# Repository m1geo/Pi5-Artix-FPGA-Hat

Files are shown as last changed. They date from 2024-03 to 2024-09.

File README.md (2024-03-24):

# Pi5-Artix-FPGA-Hat

An AMD/Xilinx Artix 50T FPGA on a Pi5 Hat with PCIe and GPIO interconnects as well as SPI programming using XC7A50T-2FGG484C.

The project uses a 4-layer PCB (which means some of the routing is a bit sub-optimal)!

The project includes pick-and-place and LCSC BoM files for JLCPCB PCBA services.

*Both SPI programming and PCIe have been tested and are functional.*

# Files

The PCB design files are inside the PCB folder, along with the schematic in the PCB/outputs/ folder.

The FPGA folder has a simple Blinky (flashing LED) and PCIe design based on the Xilinx Reference Design with some small mods.

The FPGA/Programmer/ folder has a script for programming the FPGA via spidev and lgpio using Xilinx Serial Slave (essentially SPI).

# Licence

MIT Licence. See the LICENCE file included for details.

Files inside FPGA/pcie_7x_0_ex/ are Copyright AMD/Xilinx. Seek their licence and terms of use if required.

# Support

This project comes without any support. Although I would like to help, I simply do not have the time to do so.

You can drop me a donation via PayPal if you have found the project useful: [PayPal Donation to M1GEO](https://www.paypal.com/paypalme/m1geo)

# Images

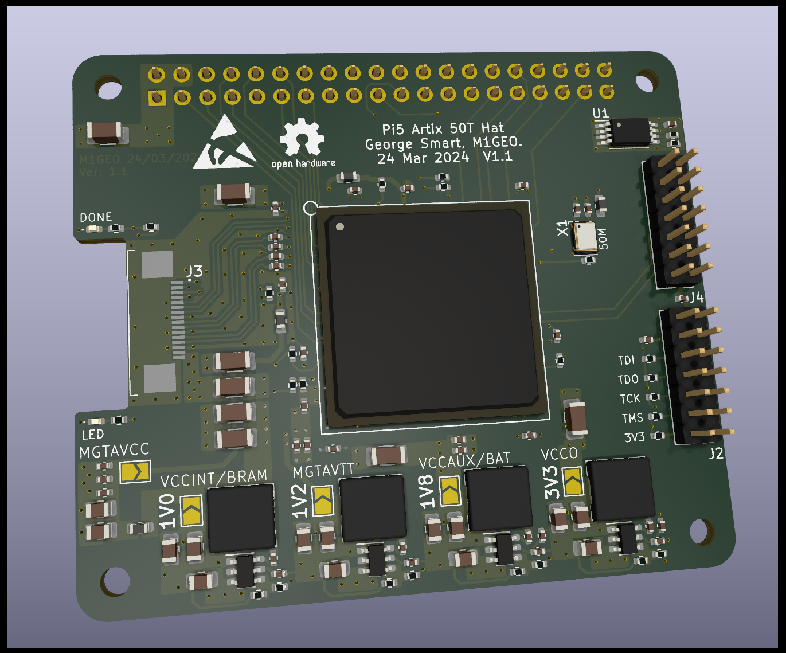
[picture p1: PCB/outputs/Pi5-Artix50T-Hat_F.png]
Front Render


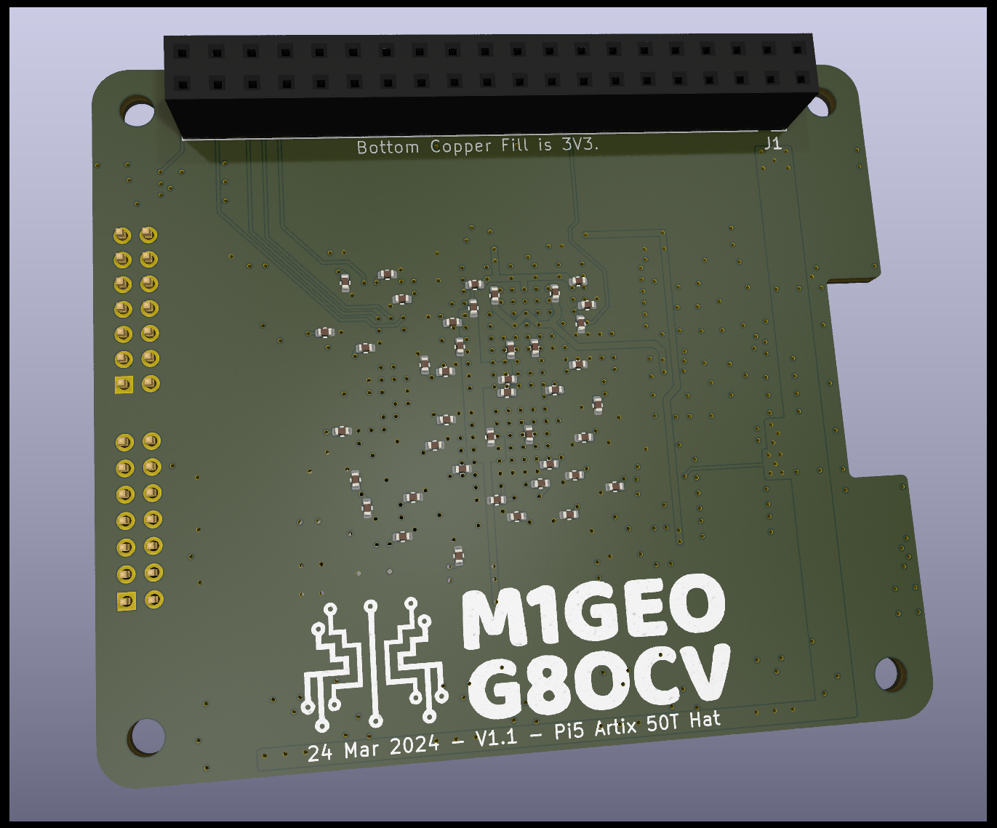
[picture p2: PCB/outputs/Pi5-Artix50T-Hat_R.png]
Rear Render


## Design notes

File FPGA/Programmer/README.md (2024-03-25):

# FPGA Programming Script Notes

Note that the `lgpio.gpiochip_open(n)` function changes between Pi4 and Pi5, with Pi4/CM4 being gpiochip 0 and Pi5 (devices with the RP1 chip) being gpiochip 4.

# FPGA Programming Script

The image below shows the entireity of the FPGA programming.

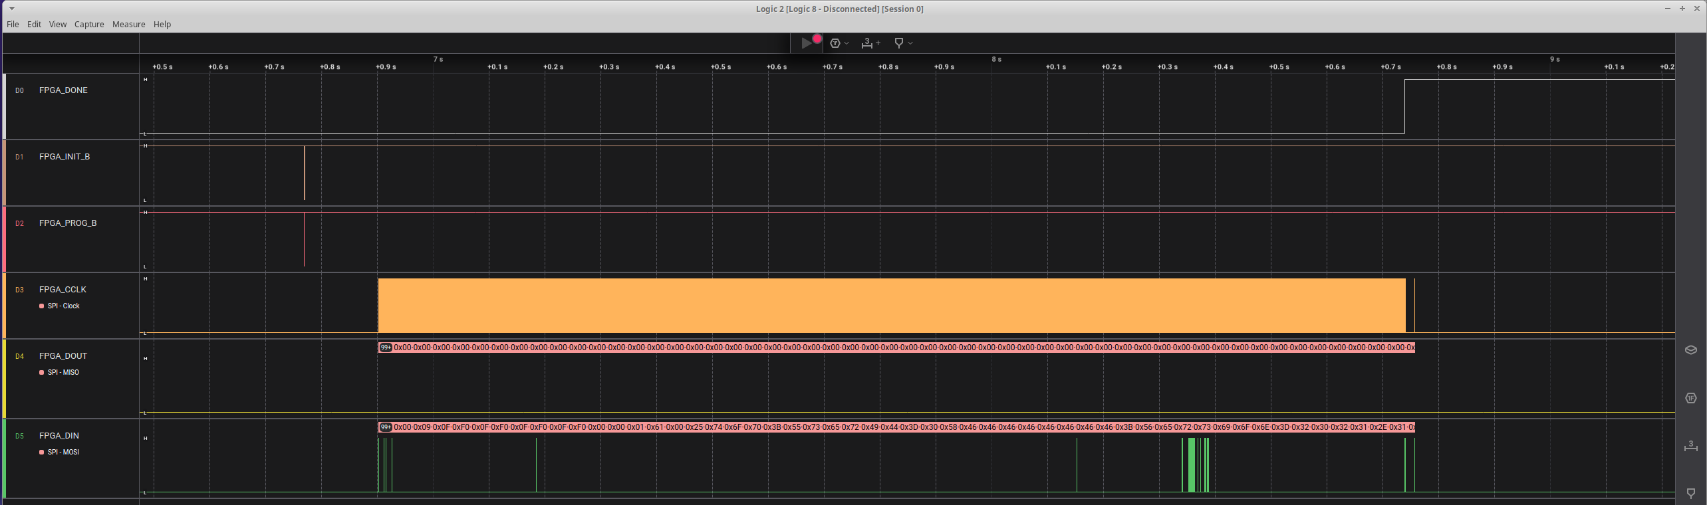
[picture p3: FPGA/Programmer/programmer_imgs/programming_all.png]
FPGA Progamming


# Init

* PROGRAM_B dropped low until INIT_B falls low, around 4us.
* Wait for INIT_B to rise, indicating FPGA is ready, around 570us.

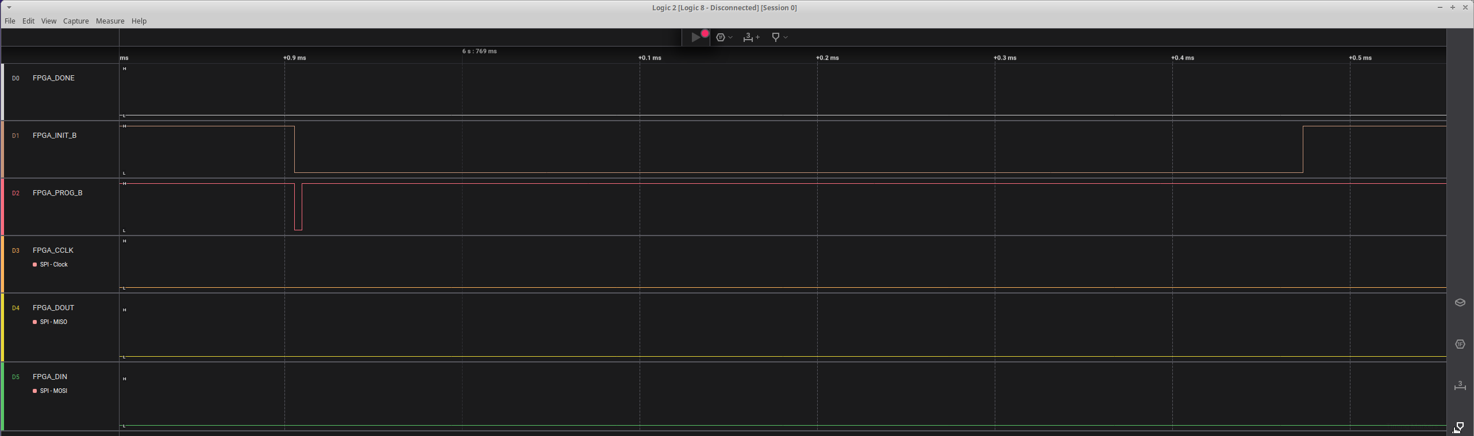
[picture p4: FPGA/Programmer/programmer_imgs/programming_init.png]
FPGA Progamming Init


# Sending the Bitfile

* Send the bitfile using SPI0 on the Pi5. The exact device doesn't matter as we aren't using the hardware chip select lines.
* The Xilinx diagrams show LSB-first. The text says to use MSB-first. The FPGA works with either. My code uses MSB-first as it's the SPI standard.
* The FPGA will happily program with a 100 MHz clock. I didn't try any faster. Debugging was done at 10 MHz.
* The Xilinx Diagrams show SPI Mode 0: that is, clock idle low, FPGA reading data on rising edge.

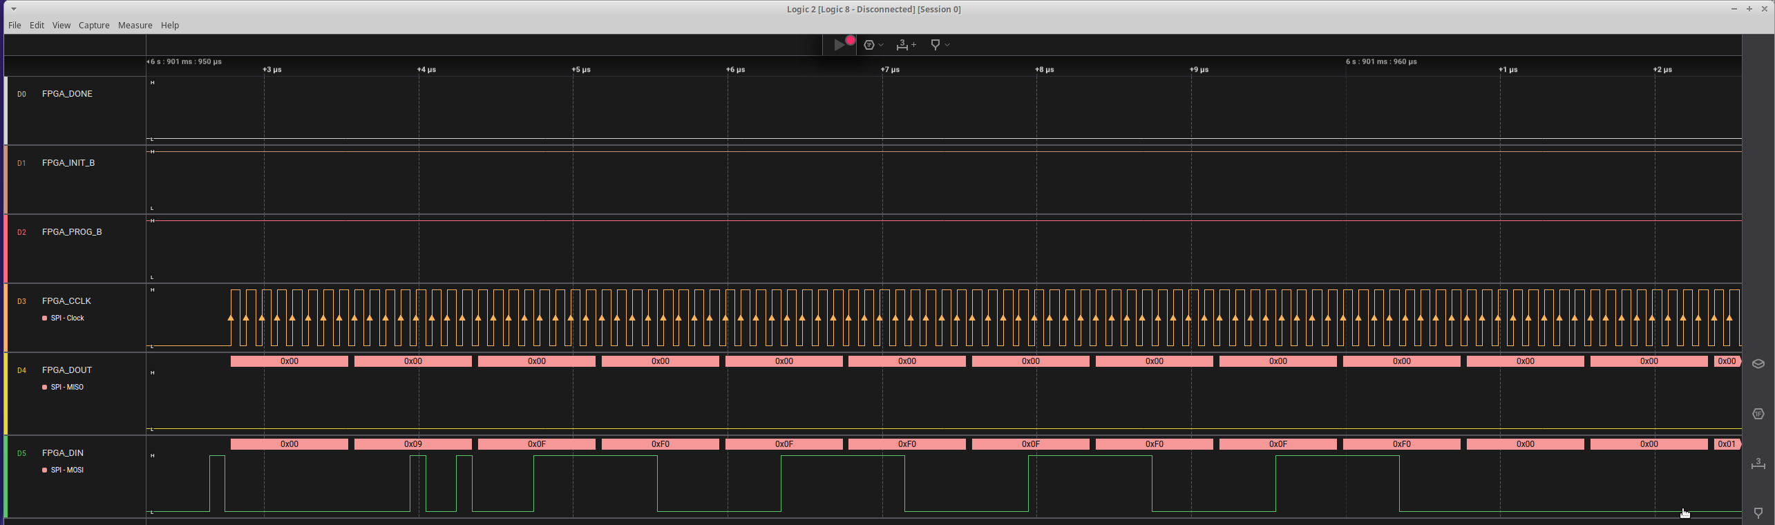
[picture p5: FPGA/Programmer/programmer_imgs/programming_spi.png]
FPGA Progamming SPI


Below shows a higlighed hexeditor view of the above SPI bytes.

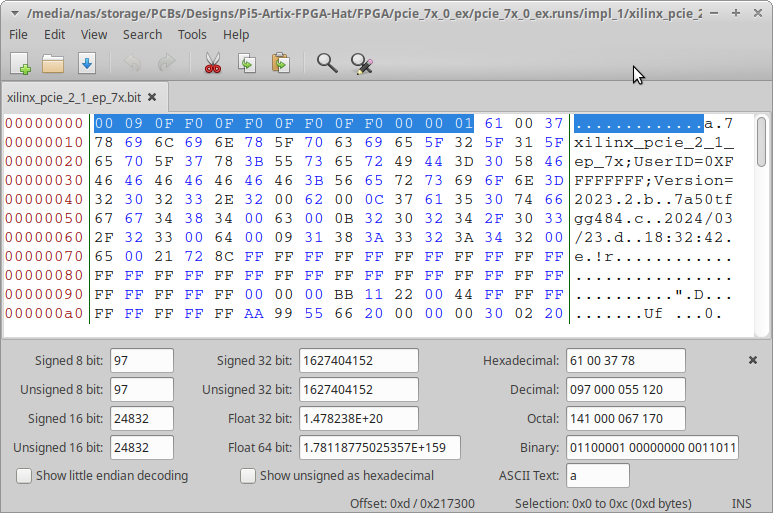
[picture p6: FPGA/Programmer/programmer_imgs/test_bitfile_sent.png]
Bitstream HEX


# Programming DONE

The programming DONE signal usually asserts before the end of the bit file. This is mentioned in the documentation.

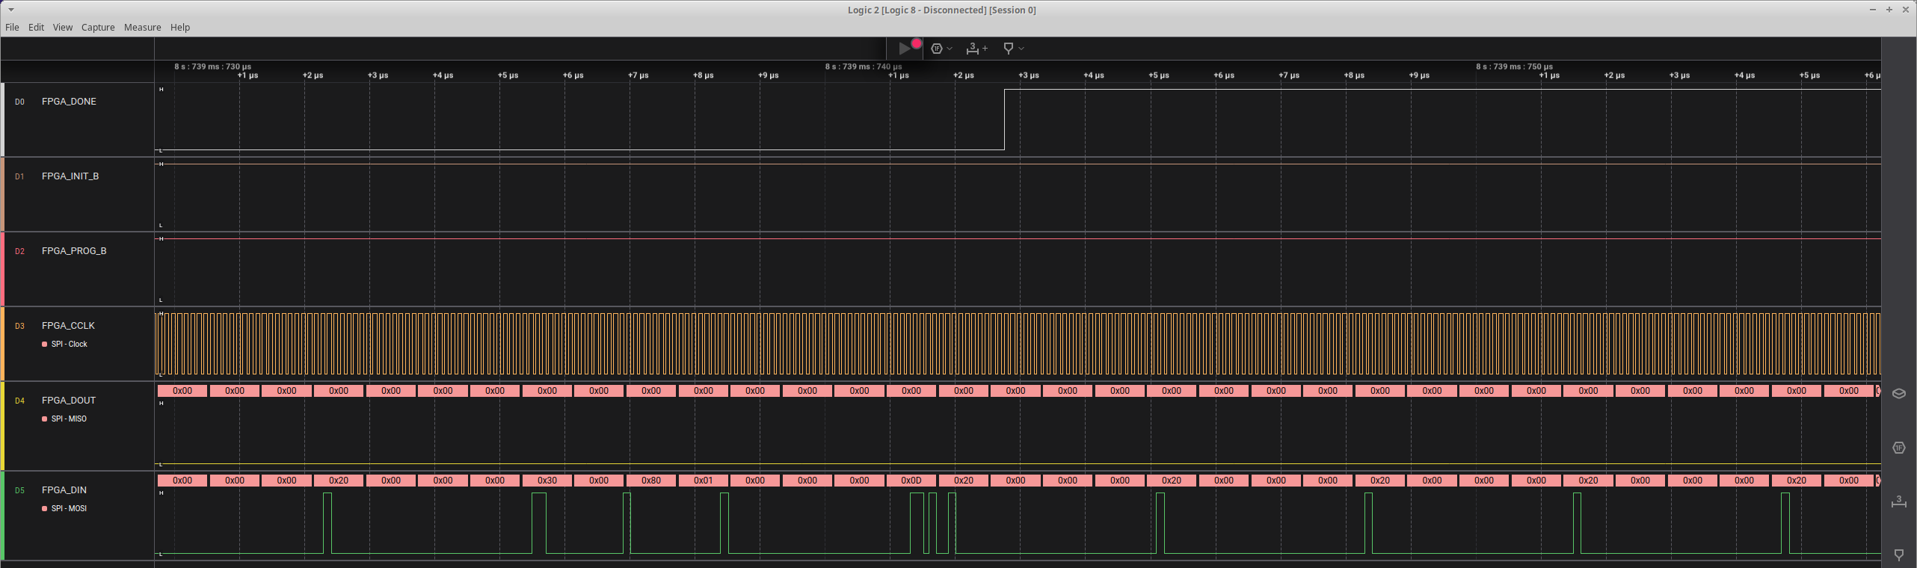
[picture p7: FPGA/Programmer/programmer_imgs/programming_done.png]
FPGA Progamming Done


# Special Start-Up Conditions

The Special Start-Up Conditions provisions for cases where the interal FPGA core needs a few external clock cycles to finish the configuration and setup process. This is referred to as compensating for 'Special Startup Conditions' and requires the Pi to send a further 8 clock cycles with DIN held high. This is accomplished by sending an 0xFF byte.

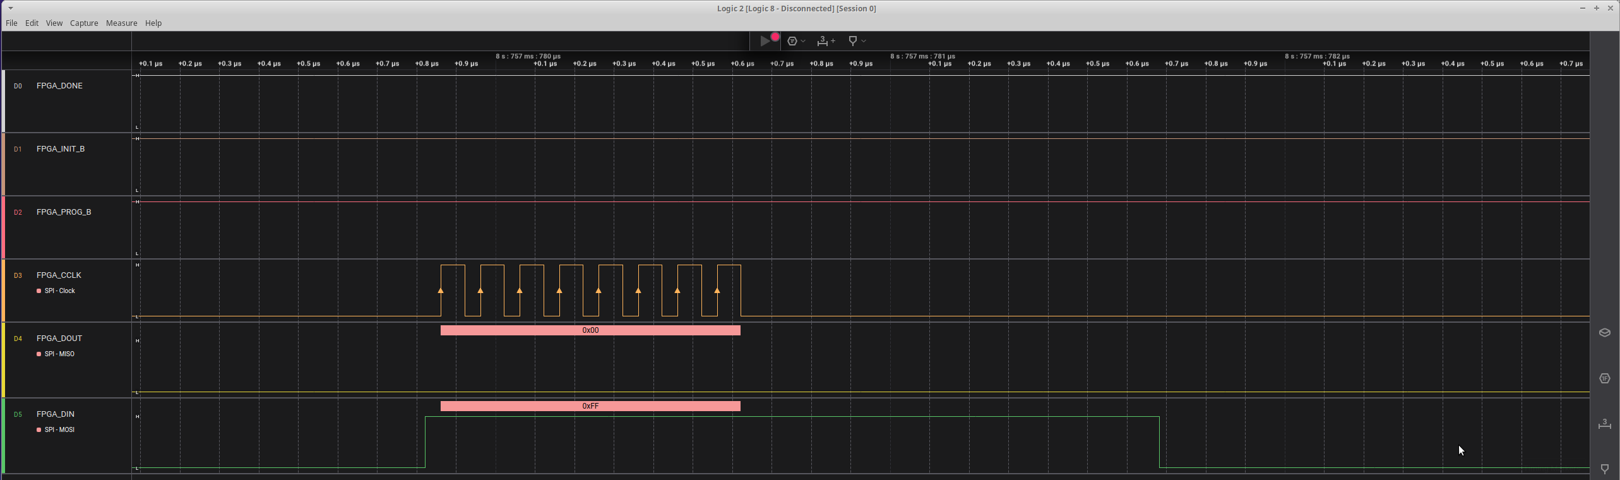
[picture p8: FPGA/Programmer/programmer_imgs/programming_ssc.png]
FPGA Progamming SSC


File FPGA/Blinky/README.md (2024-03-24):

# Blinky FPGA Image

This folder contains a bit file & sources that can be programmed using the programmer script into the FPGA.

It takes the 50 MHz reference clock and generates a 3 Hz LED flashing.  That's it. Simple.

No project here, but you can figure this one out!

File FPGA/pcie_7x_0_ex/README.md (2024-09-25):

# PCIe Gen2 x1 FPGA Image

This folder contains the Vivado project for a PCIe Gen2 x1 test system. It's simply the PCIe 7-Series Reference Design by Xilinx, with some small tweaks to make it work on the Pi5.

This design is recognised by Linux on the Ras Pi 5:

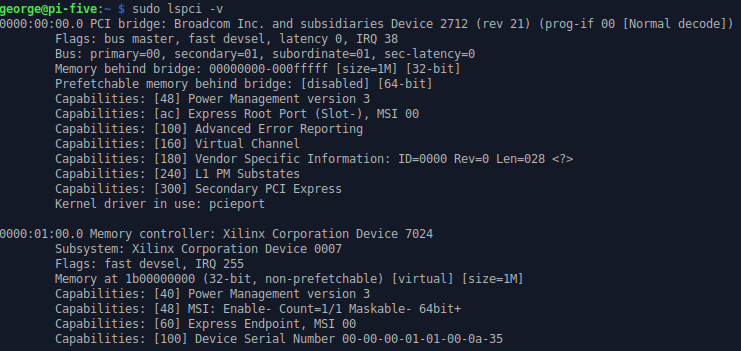
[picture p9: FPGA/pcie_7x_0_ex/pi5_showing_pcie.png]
Linux on Pi5 Showing FPGA via PCIe


# Rescanning the PCIe Bus

Once you have programmed the FPGA, the Pi will not immediately see it, since the Pi is a bit weird with hotplug detection, etc., so you'll need to run the following to kick the PCIe controller. Not really sure what this does, but, it works...

`echo 1000110000.pcie > /sys/bus/platform/drivers/brcm-pcie/bind` (Pi5)

`echo fd500000.pcie > /sys/bus/platform/drivers/brcm-pcie/bind` (Pi4/CM4)

# Legals

The files in the project mostly belong to AMD/Xilinx through their reference design. I am not asserting any claims over these files. They are provided for convenience.

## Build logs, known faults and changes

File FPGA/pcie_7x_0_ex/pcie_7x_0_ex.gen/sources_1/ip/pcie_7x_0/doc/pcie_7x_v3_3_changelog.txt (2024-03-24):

2023.2:
 * Version 3.3 (Rev. 20)
 * General: Rebrand to AMD copyright information
 * Revision change in one or more subcores

2023.1.2:
 * Version 3.3 (Rev. 19)
 * No changes

2023.1.1:
 * Version 3.3 (Rev. 19)
 * No changes

2023.1:
 * Version 3.3 (Rev. 19)
 * Revision change in one or more subcores

2022.2.2:
 * Version 3.3 (Rev. 18)
 * No changes

2022.2.1:
 * Version 3.3 (Rev. 18)
 * No changes

2022.2:
 * Version 3.3 (Rev. 18)
 * Revision change in one or more subcores

2022.1.2:
 * Version 3.3 (Rev. 17)
 * No changes

2022.1.1:
 * Version 3.3 (Rev. 17)
 * No changes

2022.1:
 * Version 3.3 (Rev. 17)
 * General: Added pcie id interface and corresponding signals
 * Revision change in one or more subcores

2021.2.2:
 * Version 3.3 (Rev. 16)
 * No changes

2021.2.1:
 * Version 3.3 (Rev. 16)
 * No changes

2021.2:
 * Version 3.3 (Rev. 16)
 * Revision change in one or more subcores

2021.1.1:
 * Version 3.3 (Rev. 15)
 * No changes

2021.1:
 * Version 3.3 (Rev. 15)
 * Revision change in one or more subcores

2020.3:
 * Version 3.3 (Rev. 14)
 * No changes

2020.2.2:
 * Version 3.3 (Rev. 14)
 * No changes

2020.2.1:
 * Version 3.3 (Rev. 14)
 * No changes

2020.2:
 * Version 3.3 (Rev. 14)
 * General: Added Zynq 7z030i,7z035i,7z045i and 7z100i device support
 * Revision change in one or more subcores

2020.1.1:
 * Version 3.3 (Rev. 13)
 * No changes

2020.1:
 * Version 3.3 (Rev. 13)
 * Revision change in one or more subcores

2019.2.2:
 * Version 3.3 (Rev. 12)
 * No changes

2019.2.1:
 * Version 3.3 (Rev. 12)
 * No changes

2019.2:
 * Version 3.3 (Rev. 12)
 * Revision change in one or more subcores

2019.1.3:
 * Version 3.3 (Rev. 11)
 * No changes

2019.1.2:
 * Version 3.3 (Rev. 11)
 * No changes

2019.1.1:
 * Version 3.3 (Rev. 11)
 * No changes

2019.1:
 * Version 3.3 (Rev. 11)
 * General: Added new device xa7k160t.
 * Revision change in one or more subcores

2018.3.1:
 * Version 3.3 (Rev. 10)
 * No changes

2018.3:
 * Version 3.3 (Rev. 10)
 * Bug Fix: Fixed JTAG debugger Issue.
 * Bug Fix: Added waviers for lint errors.
 * Revision change in one or more subcores

2018.2:
 * Version 3.3 (Rev. 9)
 * Bug Fix: Updated MSIX TABLE & PBA OFFSET parameters. Which effects MSI-X functionality
 * Revision change in one or more subcores

2018.1:
 * Version 3.3 (Rev. 8)
 * General: Added support for xa7a12t(cpg238,csg325) and xa7a25t(cpg238,csg325) devices
 * Revision change in one or more subcores

2017.4:
 * Version 3.3 (Rev. 7)
 * General: Removed 'xx' in the Interface values
 * Revision change in one or more subcores

2017.3:
 * Version 3.3 (Rev. 6)
 * Bug Fix: Updated arrow colors for JTAG debugger LTSSM graph
 * Feature Enhancement: Enabled support for cpg238 package for devices - xc7a12t,xc7a12ti,xc7a12tl,xc7a25t,xc7z25ti and xc7a25tl
 * Revision change in one or more subcores

2017.2:
 * Version 3.3 (Rev. 5)
 * Revision change in one or more subcores

2017.1:
 * Version 3.3 (Rev. 4)
 * Bug Fix: Removed unwanted display messages
 * Bug Fix: Removed option to select 250Mhz of UserClk_freq (AXI Interface Frequency) for the devices xc7z015,xc7z15i and xc7z12s since the timing does not meet
 * Feature Enhancement: Added JTAG debugger support to debug LTSSM, Reset sequence and Rx detect sequence.User option is added in the 'Add.Debug Options' GUI page
 * Revision change in one or more subcores

2016.4:
 * Version 3.3 (Rev. 3)
 * General: Added support for xc7a12tl and xc7a25tl devices
 * Revision change in one or more subcores

2016.3:
 * Version 3.3 (Rev. 2)
 * Bug Fix: Updated text in core configuration GUI to display Capabilities Register value as 0x0142 when Slot Implemented option is selected for Rootport Mode
 * Other: Added support for xc7a12t,xc7a12t,xc7a25t,xc7a25ti and xc7z012s devices
 * Revision change in one or more subcores

2016.2:
 * Version 3.3 (Rev. 1)
 * Reduced the number of characters on a single line by making a multi-line attribute assignment.
 * Added CDC registers to the pl_phy_lnk_up and pl_received_hot_rst PCIe outputs.
 * Revision change in one or more subcores

2016.1:
 * Version 3.3
 * Modified the width of pipe_tx_*_sigs, common_commands_in and common_commands_out
 * Added Tandem support for xc7z035
 * Modified the mapping of logical and physical external pipe interface ports for End Point configurations so that it can be connected to Root Port instance directly
 * Fixed issue with the default values of 'Base Class Menu' and 'Sub Class Interface Menu' and 'Class Code' update when Lookup Assistant option is used
 * Removed the dependency of 'Include Shared Logic(clocking)in example design' on 'External PIPE Interface' pipe mode simulation option.No changes made to the 'Enable Pipe mode Simulation' option
 * Revision change in one or more subcores

2015.4.2:
 * Version 3.2 (Rev. 1)
 * No changes

2015.4.1:
 * Version 3.2 (Rev. 1)
 * No changes

2015.4:
 * Version 3.2 (Rev. 1)
 * Fixed unresolved instances of sys_clk_gen used in pipe mode simulations. This module is now delivered in 'source' directory

2015.3:
 * Version 3.2
 * For EXTERNAL PIPE INTERFACE mode, a new file xil_sig2pipe.v is delivered in the simulation directory and it replaces the phy_sig_gen.v. BFM/VIP’s should interface with the xil_sig2pipe instance in board.v
 * IP revision number added to HDL module, library, and include file names, to support designs with both locked and upgraded IP instances
 * Revision change in one or more subcores

2015.2.1:
 * Version 3.1 (Rev. 1)
 * No changes

2015.2:
 * Version 3.1 (Rev. 1)
 * Fixed GTP DRP write issue - (Xilinx Answer 62770)
 * Added support for xq7z100 device
 * Added support for Post Synthesis/Implementation netlist simulation for EP/Verilog mode, for non-PIPE mode only

2015.1:
 * Version 3.1
 * Added support for xc7a35ti,xc7a50ti,xc7a75ti,xc7a100ti and xc7a200ti devices.
 * Added non-default input port pipe_txinhibit.
 * Fixed issue with invalid link width and speeds for -1 speed grade for devices xc7z030i and xc7z015i devices (x8 is not supported and incase of xc7z015i only Gen1 speeds are supported when speedgrade -1 is selected).
 * Added support for new packages: fbv484,fbv676,ffv1156,ffv900,fbv900 and ffv901
 * Added shared logic support for RP configuration.
 * Modified the External Pipe Interface as Master for Rootport configuration and Slave for Endpoint and Legacy Endpoint configurations.
 * Update to generate a 100MHz icap_clk for tandem configurations rather than using the ref_clk input.
 * Removed 250Mhz User clock frequency option for all -1,-1I,-1M,-1Q,-1L speedgrades of Artix7 family.

2014.4.1:
 * Version 3.0 (Rev. 4)
 * No changes

2014.4:
 * Version 3.0 (Rev. 4)
 * Enhancement to allow debug cores to work better within Tandem designs. Build_stage1.tcl now runs befor place_design and handles bscan primitives.
 * Added support for Artix7 xc7a15t, xc7a15tl and xa7a15t devices
 * Added support for Zynq xc7z035 device
 * Changed the pipe mode simulation options in GUI to radio buttons (No change in the functionality)

2014.3:
 * Version 3.0 (Rev. 3)
 * Enabled PIPE Sim support for Root Port configuration
 * Added support for Kintex7 Low voltage (0.9v) variants, for only Gen1 speed
 * Added support for Kintex7 Defense grade Low voltage (0.9v) variants, for only Gen1 speed
 * Fixed CPLL Power spike on power up issue (AR59294)

2014.2:
 * Version 3.0 (Rev. 2)
 * Added AZynq7030 device support
 * Added QArtix 50t device support
 * Enabled PIPE simulation and External PIPE interface support only when shared logic option Shared Logic (clocking) in example design is selected

2014.1:
 * Version 3.0 (Rev. 1)
 * Added Zynq7015 device support
 * Added 35t,50t and 75t support for Artix7l and Aartix7 devices
 * Added cpg236 and csg325 packages support for Artix7 devices
 * Enabled Tandem PROM configuration support for Zynq 7030 and for Zynq7045 devices
 * Enabled Tandem Configuration support for Kintex 420T device
 * Changed the directory structure of the core without affecting the design hierarchy

2013.4:
 * Version 3.0
 * Added XC7Z200TSBG484 device support
 * Added support Artix7 35t, 50t and 75t devices
 * Added port level enablement for icap and startup signal interfaces
 * Added 3 new ports - pipe_rxstatus, pipe_eyescandataerror and pipe_dmonitordout to the transceiver debug interface
 * Added logic to power down CPLL until it is required during the PCIe link bring-up

2013.3:
 * Version 2.2
 * Reduced Warnings in Simulations
 * Reduced Warnings in Synthesis
 * Implemented Shared Logic for Clocking and Transeciver GT Common blocks to include either in core or example design
 * Implemented Tarnsceiver Core Debug interface. Brought the debug signals to the port level
 * Brought the Ext GT DRP signals upto the core top port level
 * Added support for IPI integrator
 * Updated xdc to match IP hierarchy
 * Added support for Cadence IES and Synopsys VCS Simulators
 * Added support for upgrade from previous versions
 * Added support for Zynq 7100 device
 * Added new pages Shared Logic and Core interface Parameters in GUI in Advanced mode
 * Added Enablement of PCIe DRP interface and made the option true by default
 * PCIe Sideband interface is broken into several smaller interfaces to connect with DMA IP in IPI
 * Added support for External PIPE interface mode

2013.2:
 * Version 2.1
 * Enhancements in the Tandem Logic - added STARTUP Premitive and new ports related to this premitive (static ports)
 * Removed the redundant blocks related to Tandem configuration logic
 * Added AER_CAP_ECRC_GEN_CAPABLE parameter in XGUI
 * Added option to select the Internal or external clocking module (Parameter PCIE_EXT_CLK)
 * Marked Artix7 (fgg484 and fbg484) and Zynq devices as production. Added GES_and_Production option for Silicon_Rev parameter. Updated the Auto-Upgrade Script
 * Added support for Artix7 and Kintex7 Lowvoltage family
 * Shortened the example design xdc file name (PG updated)
 * IPI Level 0 Support
 * Added OOC flow support
 * Fixed CDC issues with GT wrappers
 * Removed the BETA tag for Tandem PROM and Tandem PCIe options
 * For x8g1, 128-bit interface width configuration, Removed the optional 250MHz. Updated the Auto-upgrade script

2013.1:
 * Version 2.0
 * Lower case ports for Verilog
 * Added Zynq Support
 * Fixed Reset Sequence issue with GTPs
 * Fixed TXOUTCLK flatline issue
 * Fixed the issue with GUI to select the optional frequency for g2x4, 128-bit configuration. Now the selection for 250Mhz optional frequency is removed as it is not supported configuration
 * Fixed XSIM issues with VHDL version of the core
 * Changed upper case portlevel signals to lower case (clocking interface for partial re-configuration and ICAP interface)
 * Added pipe_mmcm_rst_n signal at the port level as input in the core top file.
 * All Kintex devices, Virtex 2000T, Artix 100t/ffg676, 200T/fbg676,ffg1156 are marked as Production. Option is added in GUI to select GES_and_Production
 * Tandem Configuration - The option is enabled independent of the Dev board selection for Kintex 325/ffg900 and Virtex 485/ffg1761/PCIe Block X1Y0
 * Tandem Confguration - Create Bin files for stage 2, Back Up & restore of bitstream generation settings

(c) Copyright 2002 - 2023 Advanced Micro Devices, Inc. All rights reserved.

This file contains confidential and proprietary information
of AMD and is protected under U.S. and international copyright
and other intellectual property laws.

DISCLAIMER
This disclaimer is not a license and does not grant any
rights to the materials distributed herewith. Except as
otherwise provided in a valid license issued to you by
AMD, and to the maximum extent permitted by applicable
law: (1) THESE MATERIALS ARE MADE AVAILABLE "AS IS" AND
WITH ALL FAULTS, AND AMD HEREBY DISCLAIMS ALL WARRANTIES
AND CONDITIONS, EXPRESS, IMPLIED, OR STATUTORY, INCLUDING
BUT NOT LIMITED TO WARRANTIES OF MERCHANTABILITY, NON-
INFRINGEMENT, OR FITNESS FOR ANY PARTICULAR PURPOSE; and
(2) AMD shall not be liable (whether in contract or tort,
including negligence, or under any other theory of
liability) for any loss or damage of any kind or nature
related to, arising under or in connection with these
materials, including for any direct, or any indirect,
special, incidental, or consequential loss or damage
(including loss of data, profits, goodwill, or any type of
loss or damage suffered as a result of any action brought
by a third party) even if such damage or loss was
reasonably foreseeable or AMD had been advised of the
possibility of the same.

CRITICAL APPLICATIONS
AMD products are not designed or intended to be fail-
safe, or for use in any application requiring fail-safe
performance, such as life-support or safety devices or
systems, Class III medical devices, nuclear facilities,
applications related to the deployment of airbags, or any
other applications that could lead to death, personal
injury, or severe property or environmental damage
(individually and collectively, "Critical
Applications"). Customer assumes the sole risk and
liability of any use of AMD products in Critical
Applications, subject only to applicable laws and
regulations governing limitations on product liability.

THIS COPYRIGHT NOTICE AND DISCLAIMER MUST BE RETAINED AS
PART OF THIS FILE AT ALL TIMES.

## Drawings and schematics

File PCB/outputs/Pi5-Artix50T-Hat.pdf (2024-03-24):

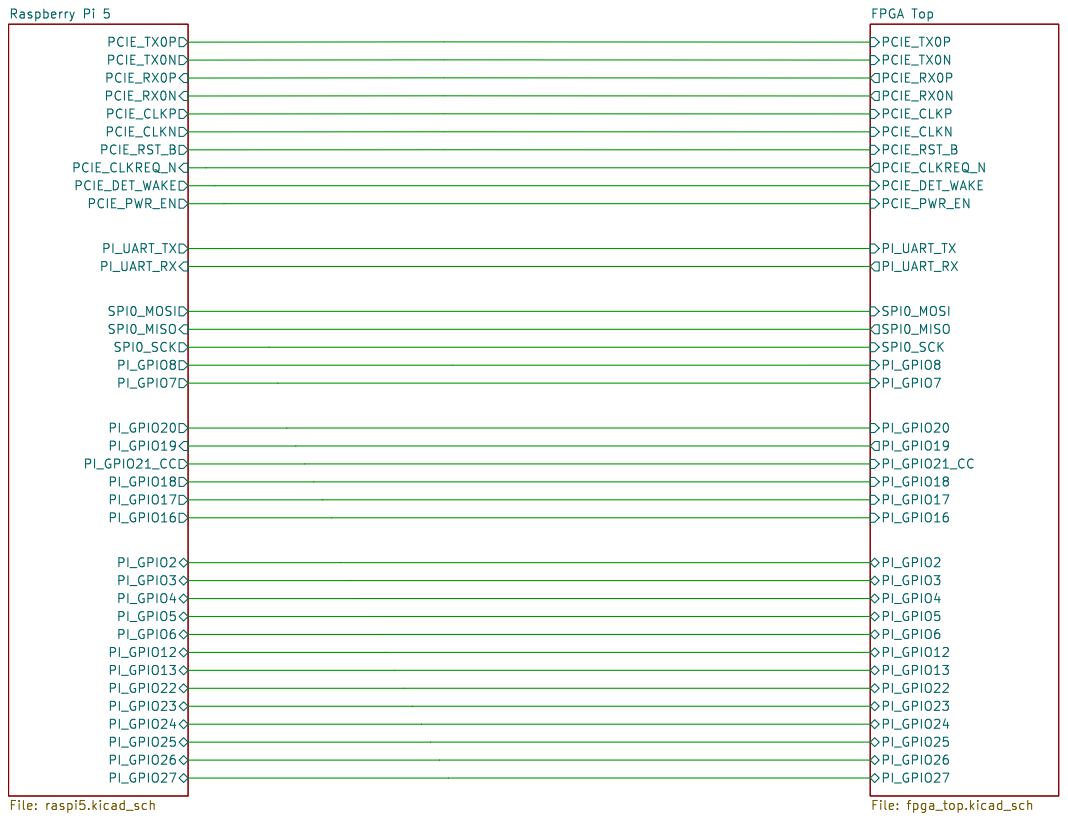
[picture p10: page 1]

https://www.george-smart.co.uk
https://github.com/m1geo/Pi5-Artix-FPGA-Hat

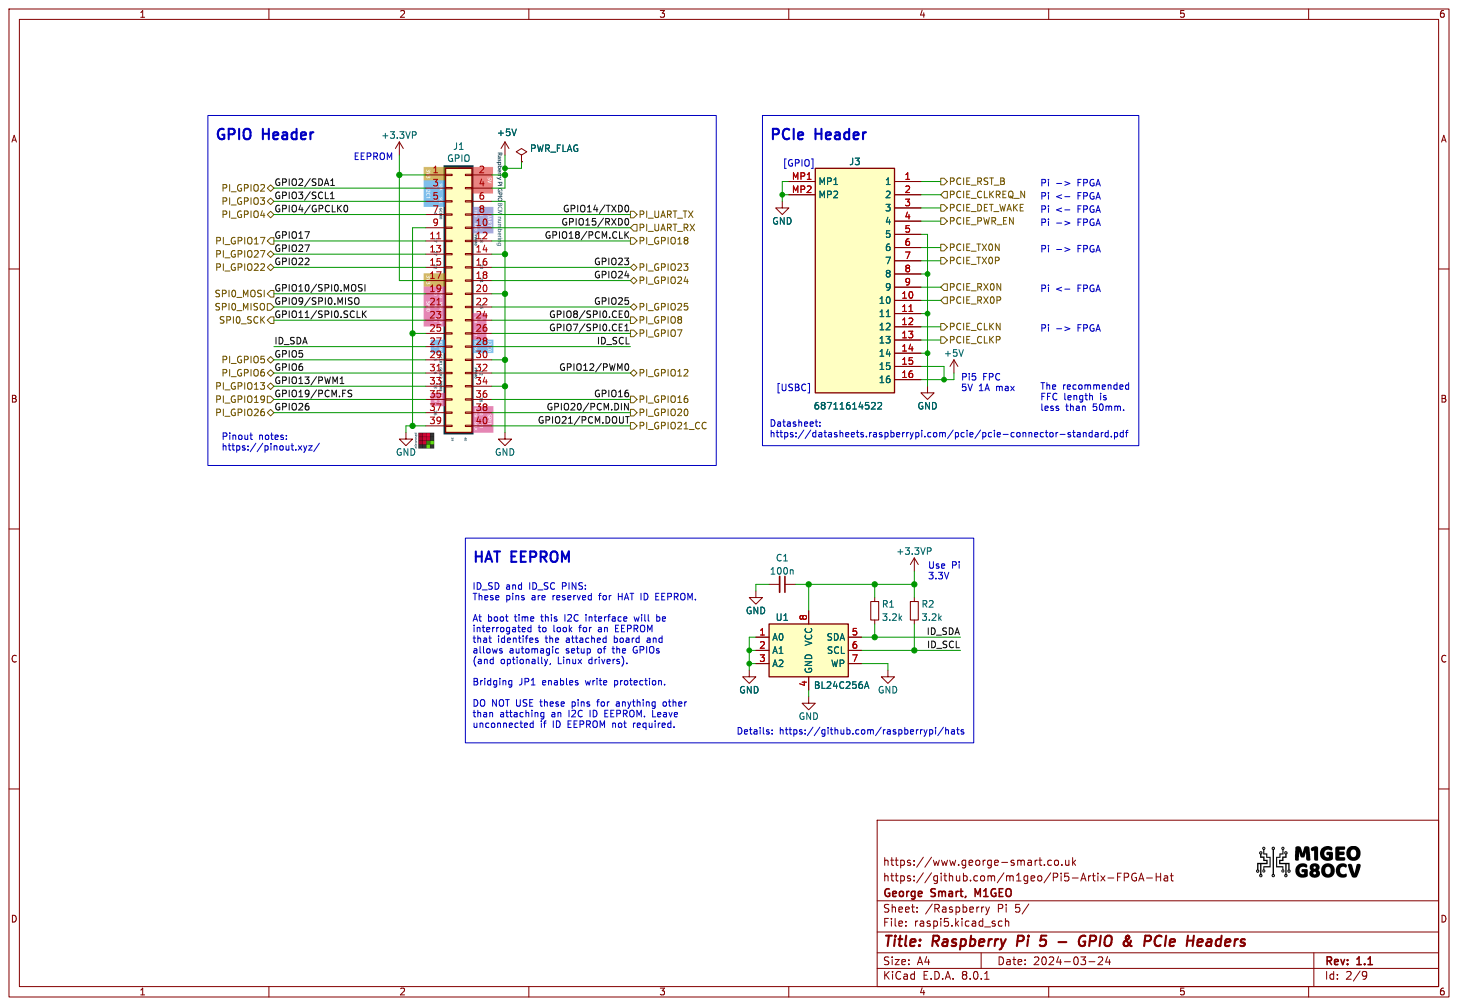
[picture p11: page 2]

[USBC] Datasheet: https://datasheets.raspberrypi.com/pcie/pcie-connector-standard.pdf Pi5 FPC

The recommended FFC length is

https://www.george-smart.co.uk R1

4 SDA 5 SCL 6 WP 7 VCC

https://github.com/m1geo/Pi5-Artix-FPGA-Hat

Id: 2/9 Title: Raspberry Pi 5 - GPIO & PCIe Headers

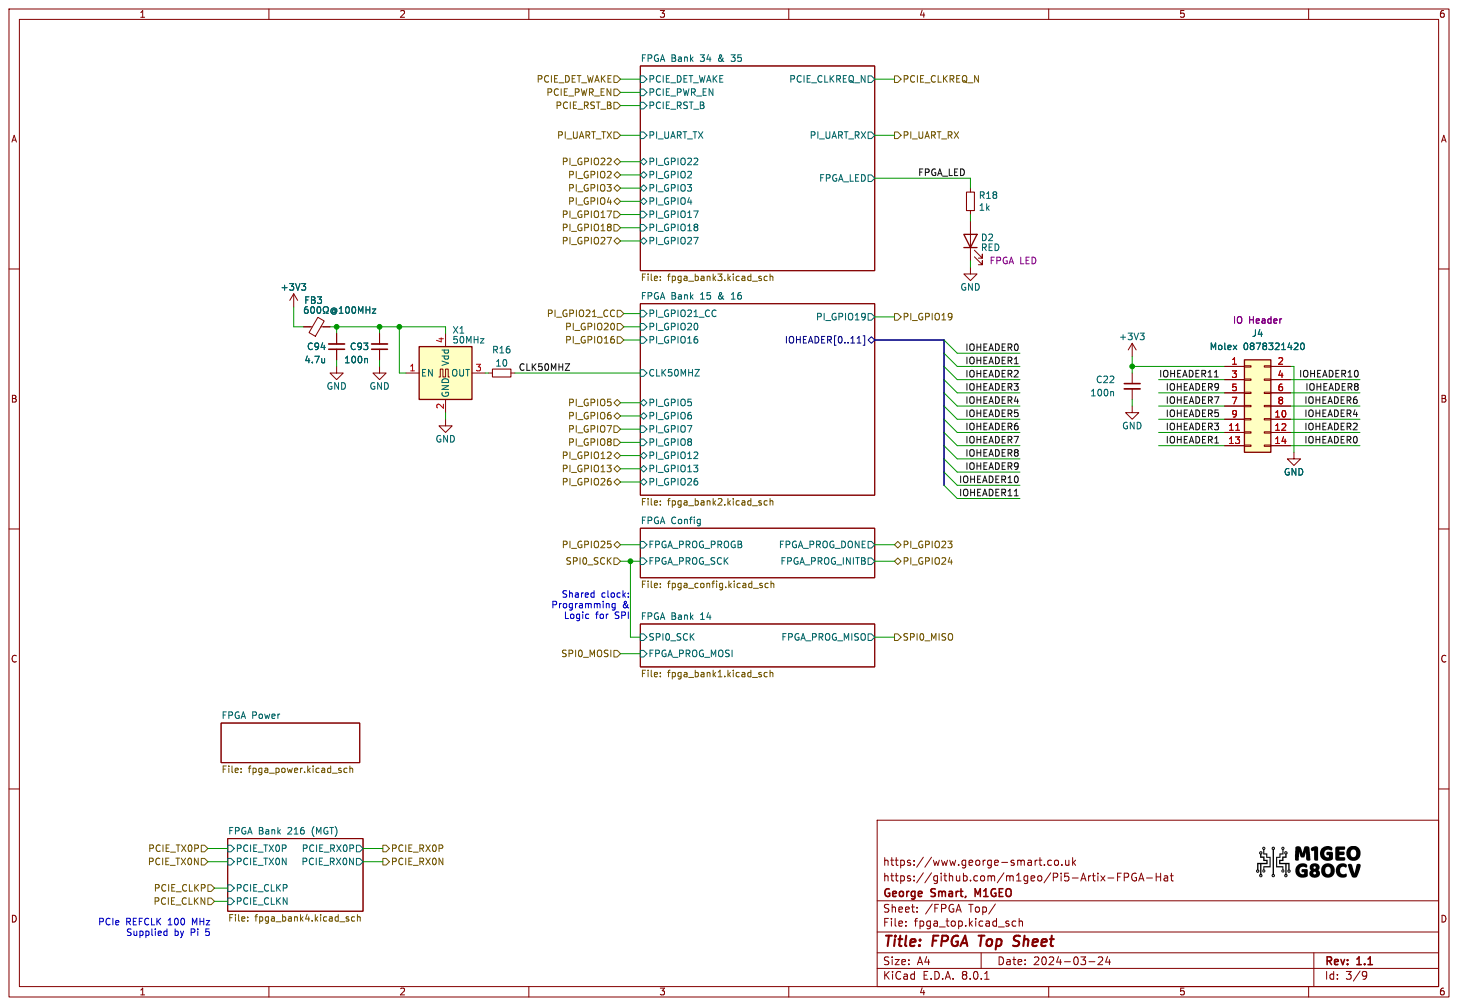
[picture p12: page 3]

FPGA Bank 216 (MGT) File: fpga_bank4.kicad_sch FPGA Power File: fpga_power.kicad_sch

https://github.com/m1geo/Pi5-Artix-FPGA-Hat
Id: 3/9 Title: FPGA Top Sheet File: fpga_top.kicad_sch Sheet: /FPGA Top/

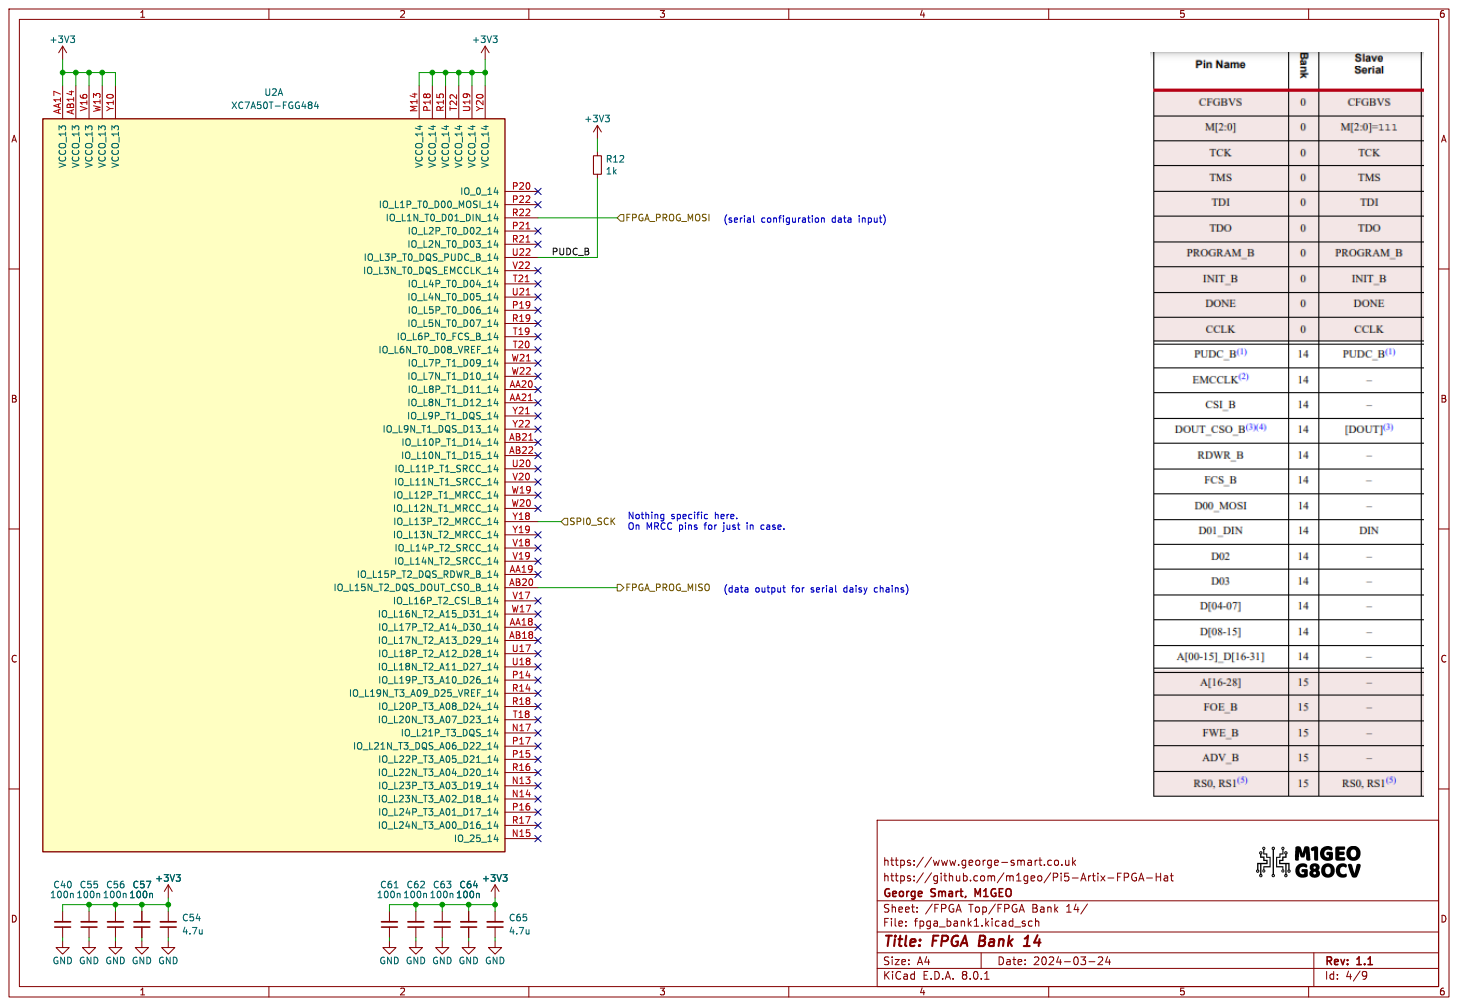
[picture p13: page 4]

(data output for serial daisy chains)

https://www.george-smart.co.uk C64

https://github.com/m1geo/Pi5-Artix-FPGA-Hat

Id: 4/9 Title: FPGA Bank 14

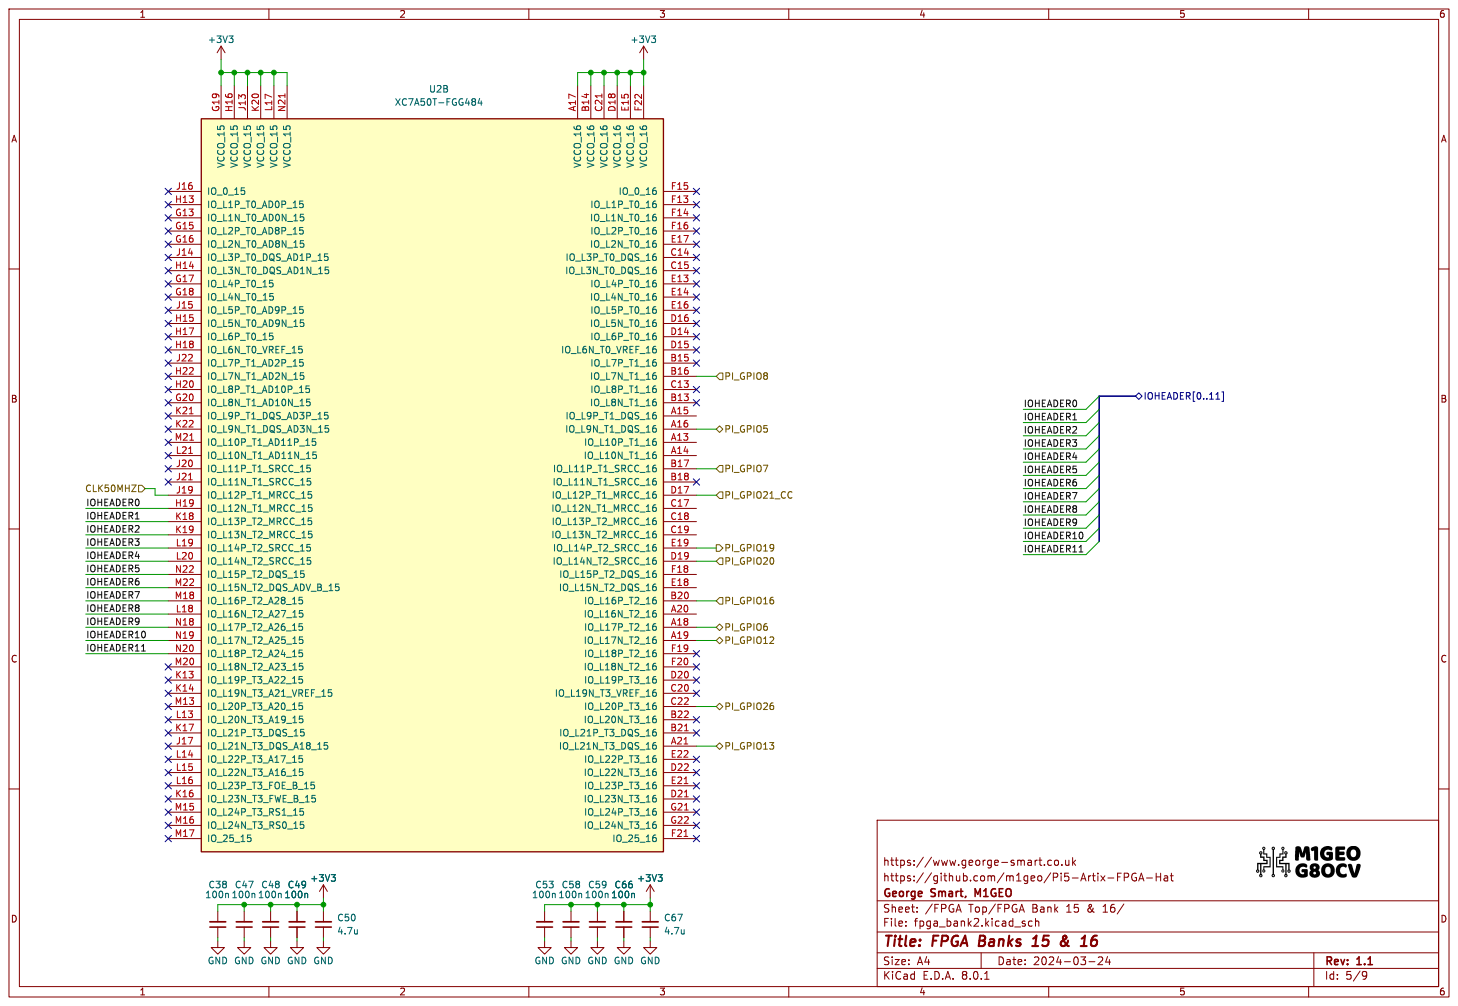
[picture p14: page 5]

https://www.george-smart.co.uk C58
4.7u +3V3 GND
100n GND GND GND GND

https://github.com/m1geo/Pi5-Artix-FPGA-Hat

Id: 5/9 Title: FPGA Banks 15 & 16

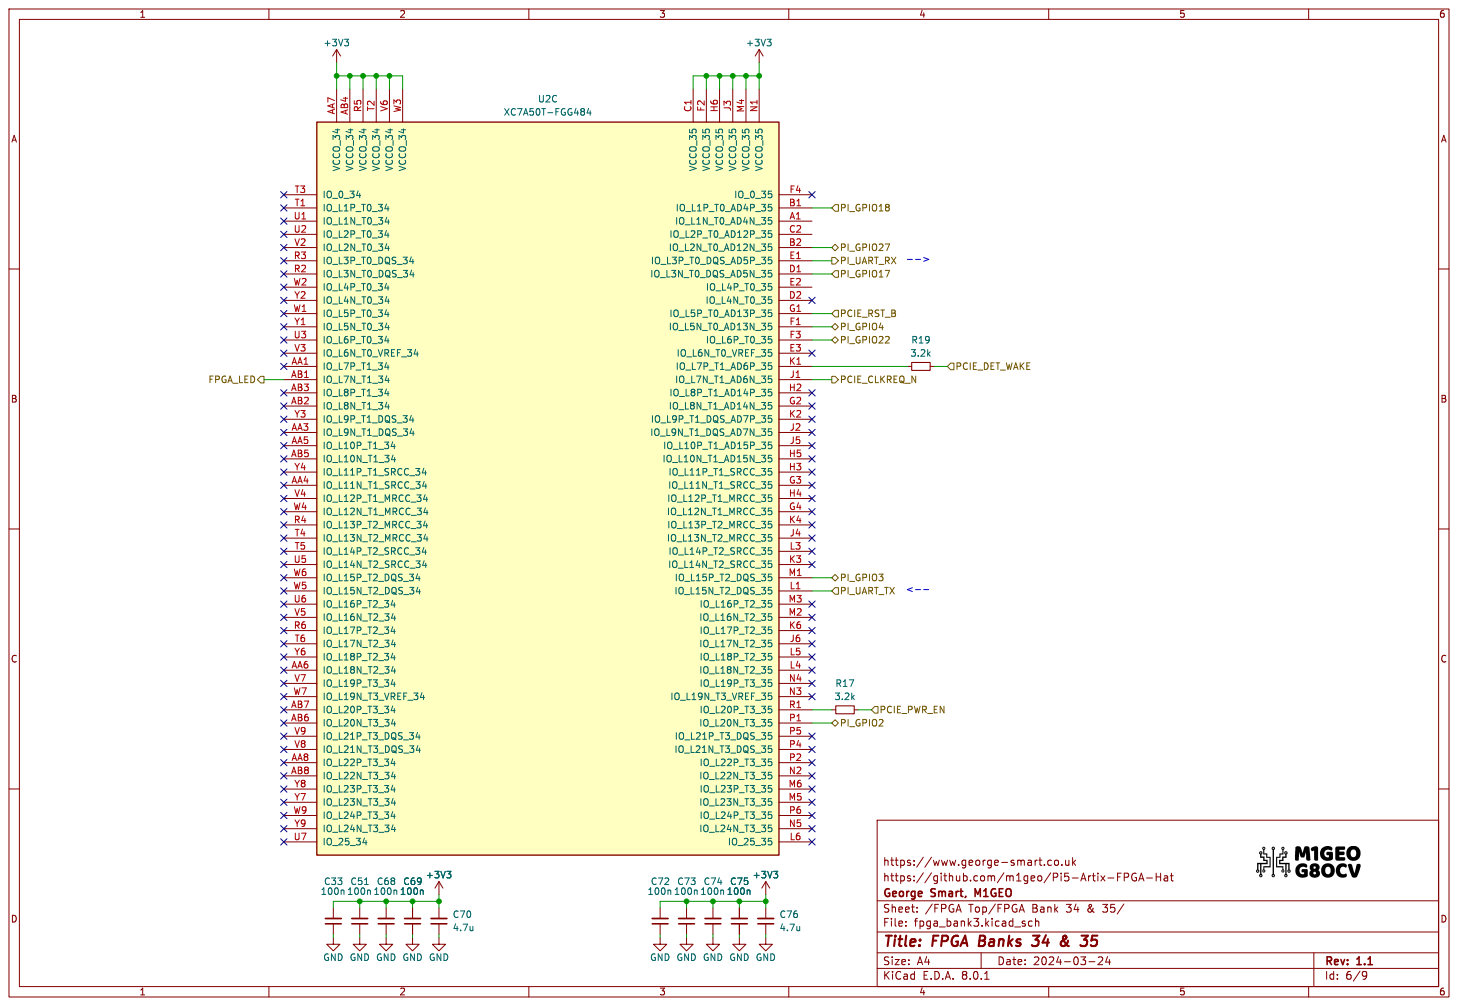
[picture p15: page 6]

https://www.george-smart.co.uk GND

https://github.com/m1geo/Pi5-Artix-FPGA-Hat

Id: 6/9 Title: FPGA Banks 34 & 35

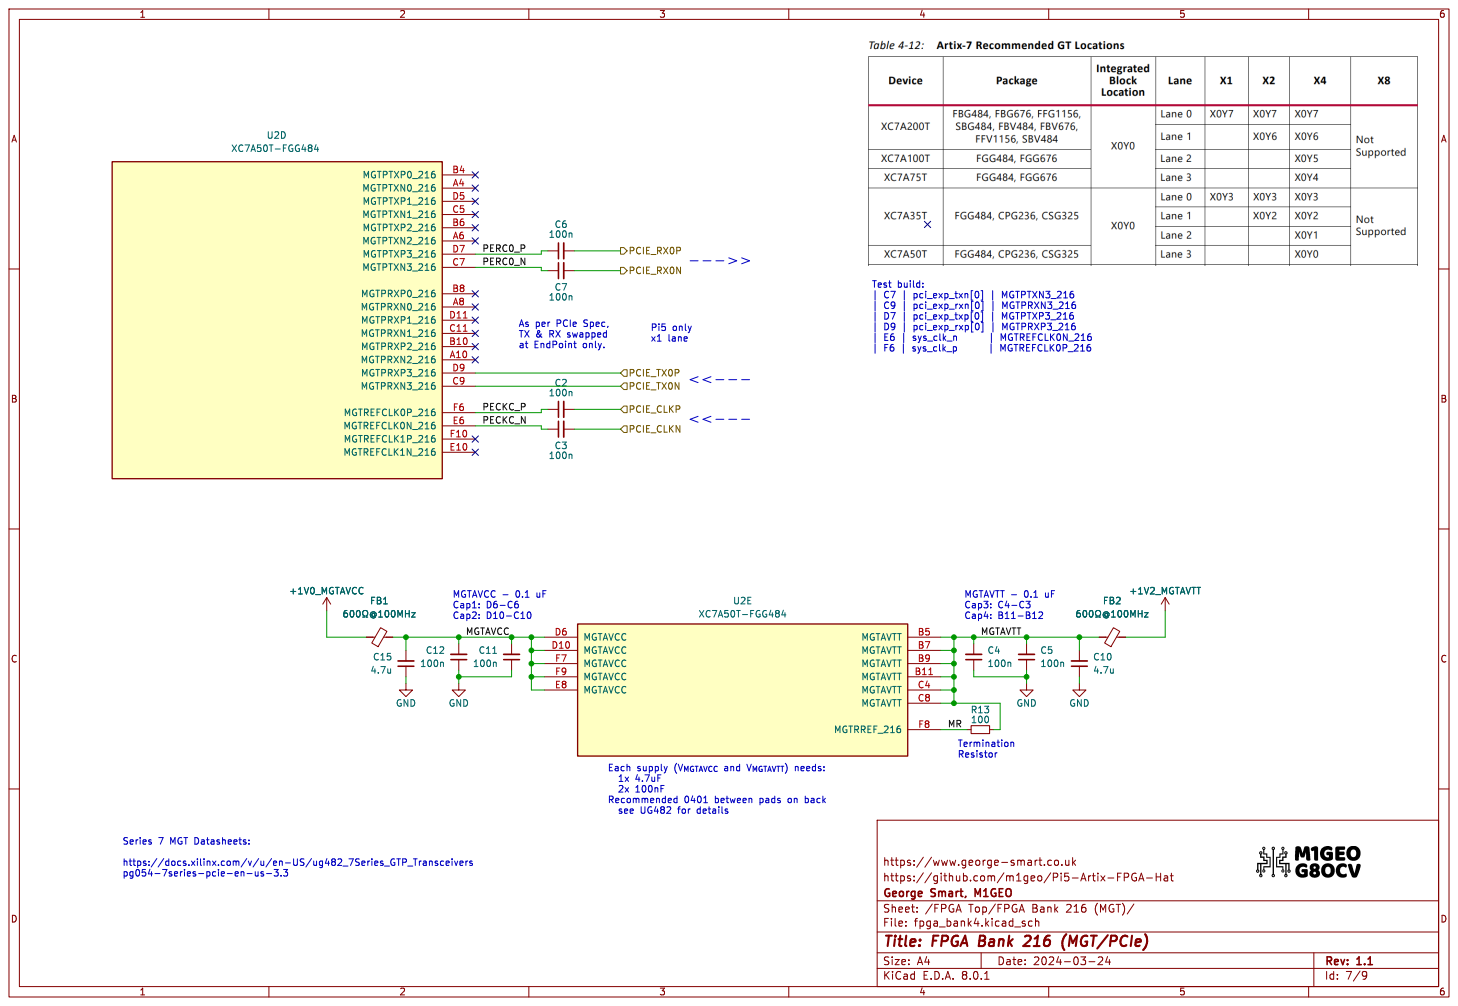
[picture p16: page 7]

see UG482 for details MGTAVCC - 0.1 uF Cap1: D6-C6 Cap2: D10-C10As per PCIe Spec, TX & RX swapped

https://github.com/m1geo/Pi5-Artix-FPGA-Hat

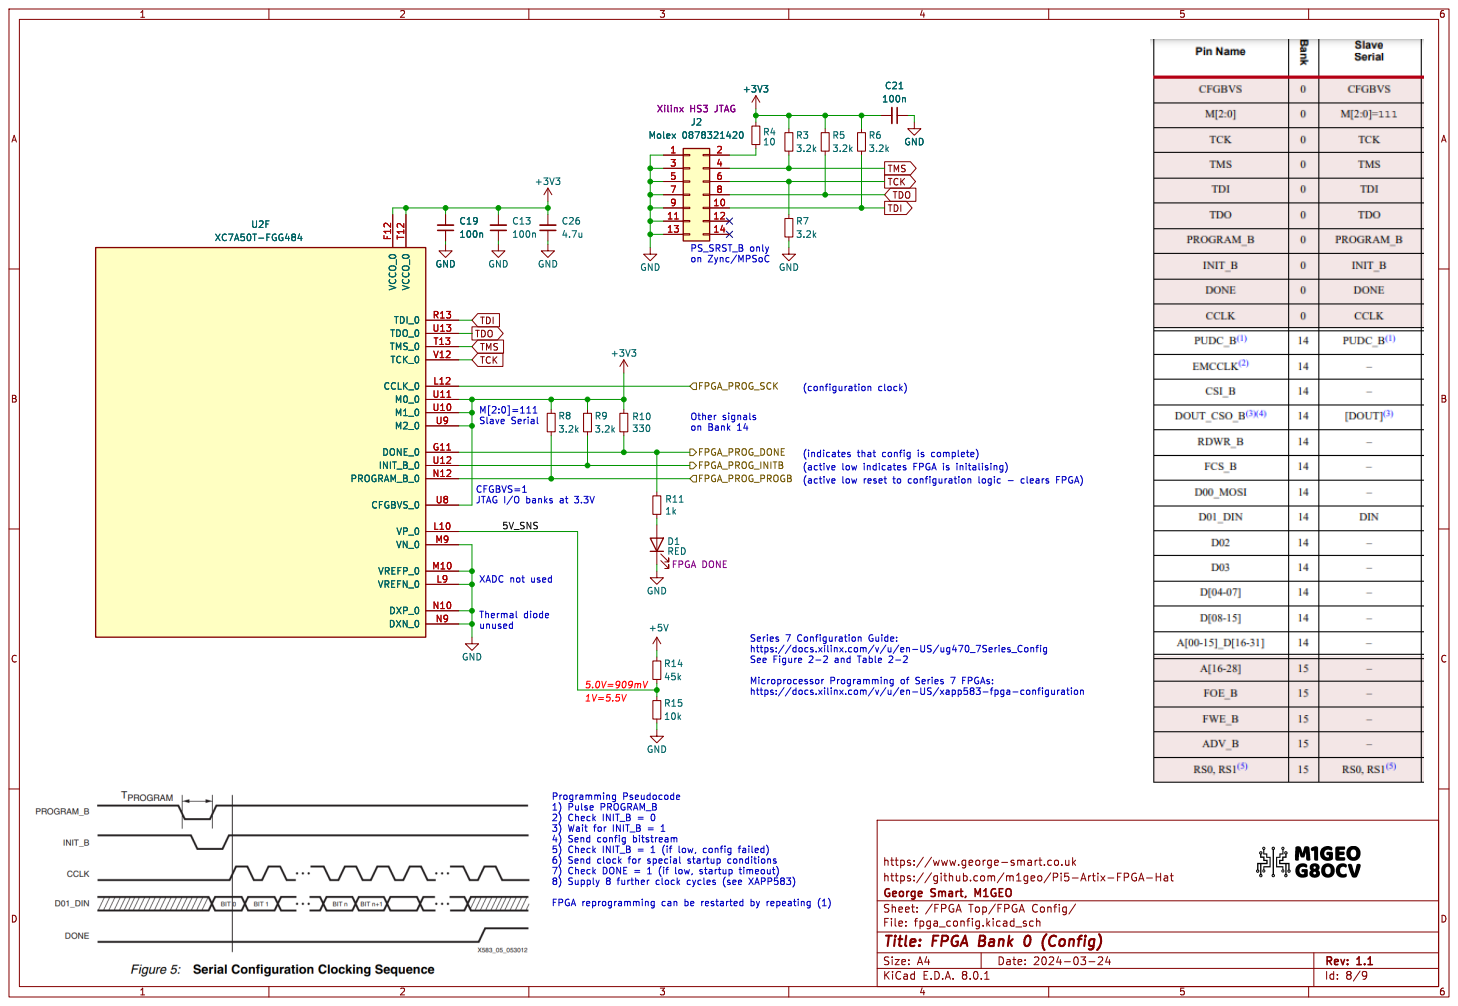
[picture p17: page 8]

https://www.george-smart.co.uk R9

1) Pulse PROGRAM_B
2) Check INIT_B = 0
3) Wait for INIT_B = 1
4) Send config bitstream
5) Check INIT_B = 1 (if low, config failed)
6) Send clock for special startup conditions 7) Check DONE = 1 (if low, startup timeout)

https://github.com/m1geo/Pi5-Artix-FPGA-Hat
Id: 8/9 Title: FPGA Bank 0 (Config) File: fpga_config.kicad_sch Sheet: /FPGA Top/FPGA Config/

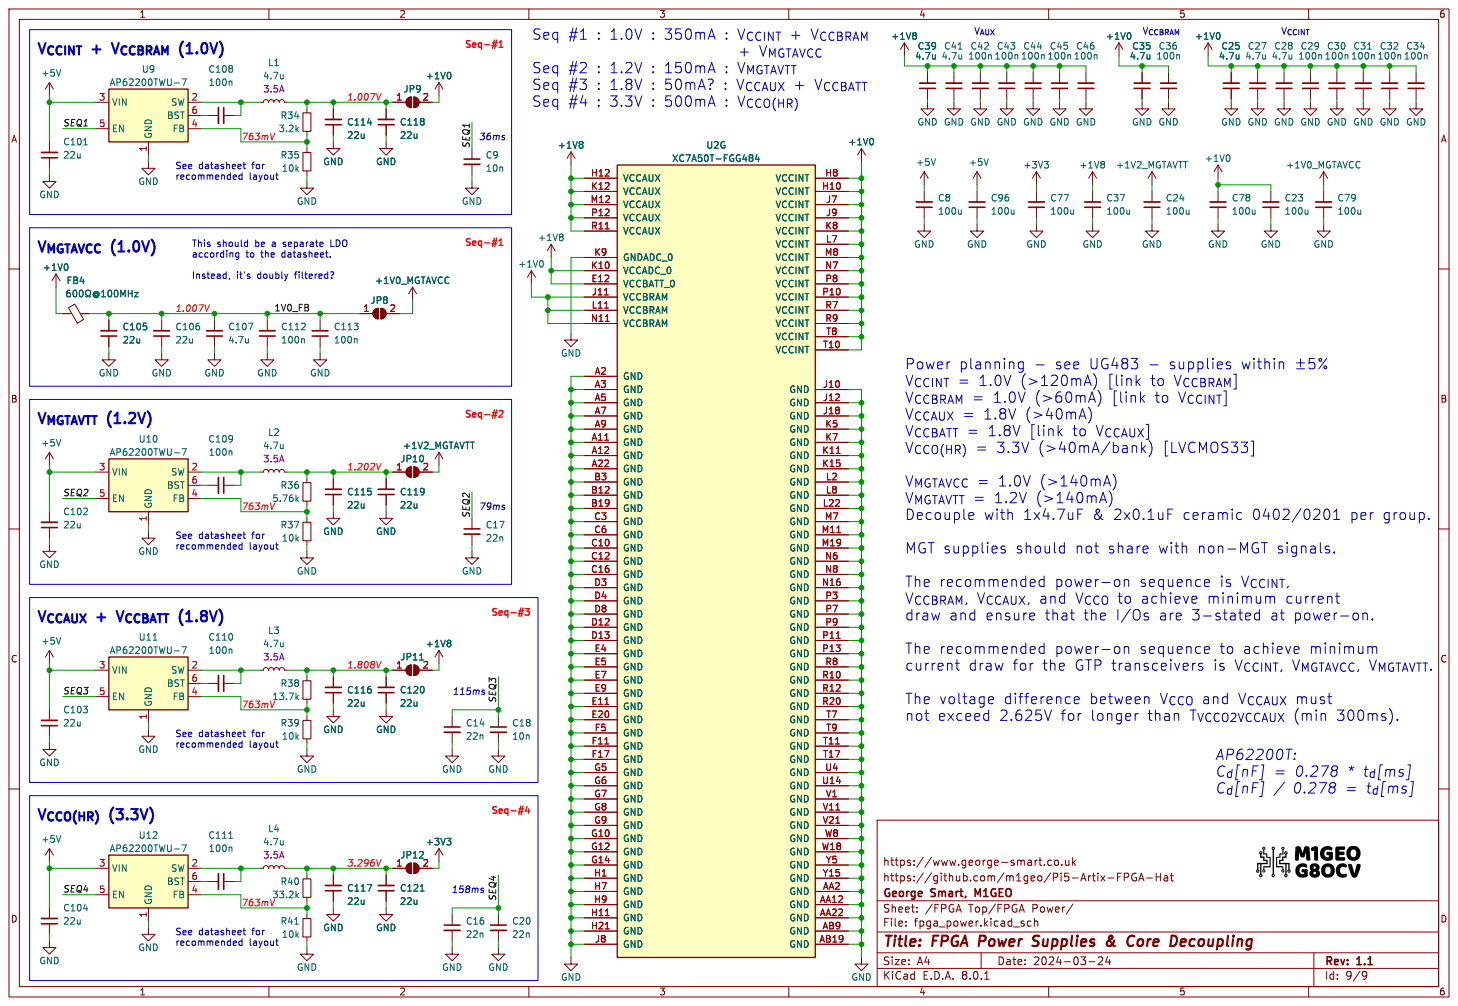
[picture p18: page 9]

Seq #1 : 1.0V : 350mA : V_{CCINT} + V_{CCBRAM} + V_{MGTAVCC}
Seq #2 : 1.2V : 150mA : V_{MGTAVTT}
Seq #3 : 1.8V : 50mA? : V_{CCAUX} + V_{CCBATT}
Seq #4 : 3.3V : 500mA : V_{CCO(HR)}

C_{d}[nF]/ 0.278 = t_{d}[ms] 763mV V_{CCINT} + V_{CCBRAM} (1.0V) This should be a separate LDO
4.7u GND

1 SW 2 VIN 3 FB 4 EN 5 BST 6 U9 AP62200TWU-7 +5V C108

Instead, it's doubly filtered?

V_{CCAUX} = 1.8V (>40mA)
V_{CCBATT} = 1.8V [link to V_{CCAUX}]

1 SW 2 VIN 3 FB 4 EN 5 BST 6 U10 AP62200TWU-7 GND GND GND GND GND GND

MGT supplies should not share with non-MGT signals.

V_{CCBRAM}, V_{CCAUX}, and V_{CCO} to achieve minimum current

1 SW 2 VIN 3 FB 4 EN 5 BST 6 U11 AP62200TWU-7 GND GND

1 SW 2 VIN 3 FB 4 EN 5 BST 6 U12 AP62200TWU-7 GND

https://www.george-smart.co.uk
https://github.com/m1geo/Pi5-Artix-FPGA-Hat

Id: 9/9 Title: FPGA Power Supplies & Core Decoupling

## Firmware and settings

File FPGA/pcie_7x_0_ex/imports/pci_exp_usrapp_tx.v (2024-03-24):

//-----------------------------------------------------------------------------
//
// (c) Copyright 2020-2024 Advanced Micro Devices, Inc. All rights reserved.
//
// This file contains confidential and proprietary information
// of AMD and is protected under U.S. and
// international copyright and other intellectual property
// laws.
//
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
// CRITICAL APPLICATIONS
// AMD products are not designed or intended to be fail-
// safe, or for use in any application requiring fail-safe
// performance, such as life-support or safety devices or
// systems, Class III medical devices, nuclear facilities,
// applications related to the deployment of airbags, or any
// other applications that could lead to death, personal
// injury, or severe property or environmental damage
// (individually and collectively, "Critical
// Applications"). Customer assumes the sole risk and
// liability of any use of AMD products in Critical
// Applications, subject only to applicable laws and
// regulations governing limitations on product liability.
//
// THIS COPYRIGHT NOTICE AND DISCLAIMER MUST BE RETAINED AS
// PART OF THIS FILE AT ALL TIMES.
//
//-----------------------------------------------------------------------------
// Project    : Series-7 Integrated Block for PCI Express
// File       : pci_exp_usrapp_tx.v
// Version    : 3.3
//
//------------------------------------------------------------------------------

`include "board_common.vh"

module pci_exp_usrapp_tx #(
parameter                                      LINK_CAP_MAX_LINK_SPEED = 4'h1
)                    (

                                               trn_td,
                                               trn_trem_n,
                                               trn_tsof_n,
                                               trn_teof_n,
                                               trn_terrfwd_n,
                                               trn_tsrc_rdy_n,
                                               trn_tsrc_dsc_n,

                                               trn_clk,
                                               trn_reset_n,
                                               trn_lnk_up_n,
                                               trn_tdst_rdy_n,
                                               trn_tdst_dsc_n,
                                               trn_tbuf_av,

                                               speed_change_done_n

                                             );

output [(64 - 1):0]                            trn_td;
output                                         trn_trem_n;
output                                         trn_tsof_n;
output                                         trn_teof_n;
output                                         trn_terrfwd_n;
output                                         trn_tsrc_rdy_n;
output                                         trn_tsrc_dsc_n;

input                                          trn_clk;
input                                          trn_reset_n;
input                                          trn_lnk_up_n;
input                                          trn_tdst_rdy_n;
input                                          trn_tdst_dsc_n;
input  [(6 - 1):0]     trn_tbuf_av;

input                                          speed_change_done_n;

parameter                                      Tcq = 1;



/* Output Variables */

reg [(64 - 1):0]          trn_td;
reg [(8 - 1):0]           trn_trem_ni;
reg                                            trn_tsof_n;
reg                                            trn_teof_n;
reg                                            trn_terrfwd_n;
reg                                            trn_tsrc_rdy_n;
reg                                            trn_tsrc_dsc_n;

/* Local Variables */

integer                                        i, j, k;
reg  [7:0]                                     DATA_STORE [4095:0];
reg  [31:0]                                    ADDRESS_32_L;
reg  [31:0]                                    ADDRESS_32_H;
reg  [63:0]                                    ADDRESS_64;
reg  [15:0]                                    COMPLETER_ID;
reg  [15:0]                                    COMPLETER_ID_CFG;
reg  [15:0]                                    REQUESTER_ID;
reg  [15:0]                                    DESTINATION_RID;
reg  [2:0]                                     DEFAULT_TC;
reg  [9:0]                                     DEFAULT_LENGTH;
reg  [3:0]                                     DEFAULT_BE_LAST_DW;
reg  [3:0]                                     DEFAULT_BE_FIRST_DW;
reg  [1:0]                                     DEFAULT_ATTR;
reg  [7:0]                                     DEFAULT_TAG;
reg  [3:0]                                     DEFAULT_COMP;
reg  [11:0]                                    EXT_REG_ADDR;
reg                                            TD;
reg                                            EP;
reg  [15:0]                                    VENDOR_ID;
reg  [9:0]                                     LENGTH; // For 1DW config and IO transactions
reg  [6:0]                                     RAND_;
reg  [9:0]                                     CFG_DWADDR;

reg  [15:0]                                    P_DEV_BDF;
reg  [31:0]                                    P_IO_ADDR;
reg  [31:0]                                    P_ADDRESS_1L;
reg  [31:0]                                    P_ADDRESS_2L;
reg  [31:0]                                    P_ADDRESS_3L;
reg  [31:0]                                    P_ADDRESS_4L;
reg  [31:0]                                    P_ADDRESS_H;

reg  [9:0]                                     P_CFG_DWADDR;


event                                          test_begin;
reg  [31:0]                                    P_ADDRESS_MASK;

reg  [31:0]                                    P_READ_DATA; // will store the results of a PCIE read completion
reg  [31:0]                                    data;
reg                                            p_read_data_valid;
reg             [31:0]                         P_WRITE_DATA;
reg  [31:0]                                    temp_register;
reg                                            error_check;

// BAR Init variables
reg             [32:0]          BAR_INIT_P_BAR[6:0];           // 6 corresponds to Expansion ROM
                                                                   // note that bit 32 is for overflow checking
reg             [31:0]          BAR_INIT_P_BAR_RANGE[6:0];     // 6 corresponds to Expansion ROM
reg             [1:0]           BAR_INIT_P_BAR_ENABLED[6:0];   // 6 corresponds to Expansion ROM
//                              0 = disabled;  1 = io mapped;  2 = mem32 mapped;  3 = mem64 mapped
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

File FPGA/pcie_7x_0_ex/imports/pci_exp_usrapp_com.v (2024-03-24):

//-----------------------------------------------------------------------------
//
// (c) Copyright 2020-2024 Advanced Micro Devices, Inc. All rights reserved.
//
// This file contains confidential and proprietary information
// of AMD and is protected under U.S. and
// international copyright and other intellectual property
// laws.
//
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
// CRITICAL APPLICATIONS
// AMD products are not designed or intended to be fail-
// safe, or for use in any application requiring fail-safe
// performance, such as life-support or safety devices or
// systems, Class III medical devices, nuclear facilities,
// applications related to the deployment of airbags, or any
// other applications that could lead to death, personal
// injury, or severe property or environmental damage
// (individually and collectively, "Critical
// Applications"). Customer assumes the sole risk and
// liability of any use of AMD products in Critical
// Applications, subject only to applicable laws and
// regulations governing limitations on product liability.
//
// THIS COPYRIGHT NOTICE AND DISCLAIMER MUST BE RETAINED AS
// PART OF THIS FILE AT ALL TIMES.
//
//-----------------------------------------------------------------------------
// Project    : Series-7 Integrated Block for PCI Express
// File       : pci_exp_usrapp_com.v
// Version    : 3.3
//--
//--------------------------------------------------------------------------------

`include "board_common.vh"

module pci_exp_usrapp_com ();


/* Local variables */

reg   [31:0]           rx_file_ptr;
reg   [7:0]            frame_store_rx[5119:0];
integer                frame_store_rx_idx;
reg   [31:0]           tx_file_ptr;
reg   [7:0]            frame_store_tx[5119:0];
integer                frame_store_tx_idx;

reg   [31:0]           log_file_ptr;
integer                _frame_store_idx;

event                  rcvd_cpld, rcvd_memrd, rcvd_memwr;
event                  rcvd_cpl, rcvd_memrd64, rcvd_memwr64;
event                  rcvd_msg, rcvd_msgd, rcvd_cfgrd0;
event                  rcvd_cfgwr0, rcvd_cfgrd1, rcvd_cfgwr1;
event                  rcvd_iord, rcvd_iowr;

initial begin

  frame_store_rx_idx = 0;
  frame_store_tx_idx = 0;

  rx_file_ptr = $fopen("rx.dat");

  if (!rx_file_ptr) begin

    $write("ERROR: Could not open rx.dat.\n");
    $finish;

  end

  tx_file_ptr = $fopen("tx.dat");

  if (!tx_file_ptr) begin

    $write("ERROR: Could not open tx.dat.\n");
    $finish;
  end
end

  /************************************************************
  Task : TSK_PARSE_FRAME
  Inputs : None
  Outputs : None
  Description : Parse frame data
  *************************************************************/

  task TSK_PARSE_FRAME;
  input    log_file;

  reg   [1:0]   fmt;
  reg   [4:0]   f_type;
  reg   [2:0]   traffic_class;
  reg     td;
  reg      ep;
  reg  [1:0]   attr;
  reg  [9:0]   length;
  reg     payload;
  reg  [15:0]   requester_id;
  reg  [15:0]   completer_id;
  reg  [7:0]   tag;
  reg  [7:0]   byte_enables;
  reg  [7:0]  message_code;
  reg  [31:0]   address_low;
  reg  [31:0]   address_high;
  reg  [9:0]   register_address;
  reg   [2:0]   completion_status;
  reg  [31:0]  _log_file_ptr;
  integer    _frame_store_idx;

  begin

  if (log_file == `RX_LOG)
    _log_file_ptr = rx_file_ptr;
  else
    _log_file_ptr = tx_file_ptr;

  if (log_file == `RX_LOG) begin

    _frame_store_idx = frame_store_rx_idx;
    frame_store_rx_idx = 0;

  end else begin

    _frame_store_idx = frame_store_tx_idx;
    frame_store_tx_idx = 0;

  end

  if (log_file == `RX_LOG) begin

    $display("[%t] : TSK_PARSE_FRAME on Receive", $realtime);

    end
  else begin

    $display("[%t] : TSK_PARSE_FRAME on Transmit", $realtime);

    end          

  TSK_DECIPHER_FRAME (fmt, f_type, traffic_class, td, ep, attr, length, log_file);  

  // decode the packets received based on fmt and f_type

  casex({fmt, f_type})

    `PCI_EXP_MEM_READ32 : begin

      $fdisplay(_log_file_ptr, "[%t] : Memory Read-32 Frame \n", $time);
      payload = 0;
      TSK_3DW(fmt, f_type, traffic_class, td, ep, attr, length, payload, _frame_store_idx, _log_file_ptr, log_file);
      
      if (log_file == `RX_LOG)
        -> rcvd_memrd;
    end

    `PCI_EXP_IO_READ : begin

      $fdisplay(_log_file_ptr, "[%t] : IO Read Frame \n", $time);
      payload = 0;
      TSK_3DW(fmt, f_type, traffic_class, td, ep, attr, length, payload, _frame_store_idx, _log_file_ptr, log_file);

      if (log_file == `RX_LOG)
        -> rcvd_iord;
    end

    `PCI_EXP_CFG_READ0 : begin

      $fdisplay(_log_file_ptr, "[%t] : Config Read Type 0 Frame \n", $time);
      payload = 0;
      TSK_3DW(fmt, f_type, traffic_class, td, ep, attr, length, payload, _frame_store_idx, _log_file_ptr, log_file);

      if (log_file == `RX_LOG) 
        -> rcvd_cfgrd0;
    end

    `PCI_EXP_COMPLETION_WO_DATA: begin

      $fdisplay(_log_file_ptr, "[%t] : Completion Without Data Frame \n", $time);
      payload = 0;
      TSK_3DW(fmt, f_type, traffic_class, td, ep, attr, length, payload, _frame_store_idx, _log_file_ptr, log_file);

      if (log_file == `RX_LOG) 
        -> rcvd_cpl;
    end

    `PCI_EXP_MEM_READ64: begin

      $fdisplay(_log_file_ptr, "[%t] : Memory Read-64 Frame \n", $time);
      payload = 0;
      TSK_4DW(fmt, f_type, traffic_class, td, ep, attr, length, payload,  _frame_store_idx, _log_file_ptr, log_file);

      if (log_file == `RX_LOG) 
        -> rcvd_memrd64;
    end

    `PCI_EXP_MSG_NODATA: begin

      $fdisplay(_log_file_ptr, "[%t] : Message With No Data Frame \n", $time);
      payload = 0;
      TSK_4DW(fmt, f_type, traffic_class, td, ep, attr, length, payload,  _frame_store_idx, _log_file_ptr, log_file);

      if (log_file == `RX_LOG) 
        -> rcvd_msg;
    end

    `PCI_EXP_MEM_WRITE32: begin

      $fdisplay(_log_file_ptr, "[%t] : Memory Write-32 Frame \n", $time);
      payload = 1;
      TSK_3DW(fmt, f_type, traffic_class, td, ep, attr, length, payload, _frame_store_idx, _log_file_ptr, log_file);
      $fdisplay(_log_file_ptr, "\n");

      if (log_file == `RX_LOG) 
        -> rcvd_memwr;
    end

    `PCI_EXP_IO_WRITE: begin

      $fdisplay(_log_file_ptr, "[%t] : IO Write Frame \n", $time);
      payload = 1;
      TSK_3DW(fmt, f_type, traffic_class, td, ep, attr, length, payload, _frame_store_idx, _log_file_ptr, log_file);
      $fdisplay(_log_file_ptr, "\n");

      if (log_file == `RX_LOG) 
        -> rcvd_iowr;
    end

    `PCI_EXP_CFG_WRITE0: begin

      $fdisplay(_log_file_ptr, "[%t] : Config Write Type 0 Frame \n", $time);
      payload = 1;
      TSK_3DW(fmt, f_type, traffic_class, td, ep, attr, length, payload, _frame_store_idx, _log_file_ptr, log_file);
      $fdisplay(_log_file_ptr, "\n");

      if (log_file == `RX_LOG) 
        -> rcvd_cfgwr0;
    end

    `PCI_EXP_COMPLETION_DATA: begin
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

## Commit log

2023-12-13 Some config pins handled
    [Pi5-Artix50T-Hat.kicad_pcb, Pi5-Artix50T-Hat.kicad_sch, fpga_bank1.kicad_sch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]
2023-12-13 Added PCB Design Guide and removed unsupported FPGA suggestion
2023-12-13 Added AC701 schematic link
2023-12-13 Added NeTV2 mainboard schematic link as it has PCIe on Artix 35T
2023-12-14 Changed FPGA to new package and hooked up some more pins
    [fpga_bank3.kicad_sch, fpga_bank4.kicad_sch, fpga_config.kicad_sch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]
2024-02-14 Schematic finished, starting layout
    [Pi5-Artix50T-Hat.kicad_pcb, Pi5-Artix50T-Hat.kicad_sch, fpga_bank1.kicad_sch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]
2024-02-14 Updated titleblock texts
    [Pi5-Artix50T-Hat.kicad_sch, fpga_bank1.kicad_sch, fpga_bank2.kicad_sch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]
2024-02-17 Changed linear PSU for SMPS and a few other changes
    [Pi5-Artix50T-Hat.kicad_pcb, fpga_config.kicad_sch, fpga_power.kicad_sch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]
2024-02-17 Started routing. More to go
    [Pi5-Artix50T-Hat.kicad_pcb, Pi5-Artix50T-Hat.kicad_sch, fpga_bank1.kicad_sch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]
2024-02-18 More routing and tinkering. Need to do non-MGT decoupling next.
    [Pi5-Artix50T-Hat.kicad_pcb, fpga_bank1.kicad_sch, fpga_bank2.kicad_sch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]
2024-02-18 Replaced wrong connector in project lib folder.
2024-02-18 Updated decoupling. Need to work out larger planes and fills.
    [Pi5-Artix50T-Hat.kicad_pcb, fpga_bank1.kicad_sch, fpga_bank2.kicad_sch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]
2024-02-19 Routing finished; Need to battle through the DRCs now. There's a few!
    [Pi5-Artix50T-Hat.kicad_pcb, fpga_bank1.kicad_sch, fpga_bank2.kicad_sch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]
2024-02-19 Removed R17 silkscreen
    [Pi5-Artix50T-Hat.kicad_pcb]
2024-02-20 Ordered boards from JLCPCB for V1
    [Pi5-Artix50T-Hat.kicad_pcb, fpga_bank1.kicad_sch, fpga_bank2.kicad_sch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]
2024-03-24 Added Python Programming Script
    [fpga_config.kicad_sch, fpga_top.kicad_sch]
2024-03-24 Adding PCIe Example
    [raspi5.kicad_sch]
2024-03-24 Moved PCB into subfolder
    [Pi5-Artix50T-Hat.kicad_pcb, Pi5-Artix50T-Hat.kicad_sch, fpga_bank1.kicad_sch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]
2024-03-24 Removed files
    [Pi5-Artix50T-Hat.kicad_pcb, Pi5-Artix50T-Hat.kicad_sch, fpga_bank1.kicad_sch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]
2024-03-24 Tidying files
    [Pi5-Artix50T-Hat.kicad_pcb, Pi5-Artix50T-Hat.kicad_sch, fpga_bank1.kicad_sch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]
2024-03-24 Updated PCB to remove MOSI-MISO cross. Updated texts. New images.
    [Pi5-Artix50T-Hat.kicad_pcb, Pi5-Artix50T-Hat.kicad_sch, fpga_bank1.kicad_sch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]
